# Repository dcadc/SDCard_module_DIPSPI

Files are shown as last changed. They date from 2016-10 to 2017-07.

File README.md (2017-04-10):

# SDCard_module_DIPSPI
這是一個和 Taiwanduino 相容的 microSD 記憶卡擴充板  
他可以直接取代原本所使用的 25AA512 EEPROM 記憶體

**使用說明**
* TaiwanDuino :   
 [/software/Taiwanduino/example][sw] 資料夾內的程式碼使用 Arduino IDE 開啟  
 預設播放檔名為 0.wav ~ 7.wav 的 PCM 編碼音訊檔  
 [安裝相對應的程式庫][libs]之後即可編譯上傳  
  
*** 
  
*Read this in other languages: [English](README.en.md), [正體中文](README.md).*  

   [sw]: <https://github.com/dcadc/SDCard_module_DIPSPI/tree/master/software/Taiwanduino/example/>
   [libs]: <https://github.com/dcadc/SDCard_module_DIPSPI/blob/master/software/Taiwanduino/README.md>

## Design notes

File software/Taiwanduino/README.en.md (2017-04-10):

# Software for Taiwanduino  
   If you have the latest Arduino IDE, you can also use *Board Manager* and *Library Manager* to download and import these automatically.
  
- Board Configs   
	 - [File] → [Preferences] → [Additional Board Manager URLs] and insert the URL below:
	   https://will127534.github.io/Taiwanduino/package_Taiwanduino_index.json   
	 - [Tools] → [Board: ""] → [Board Manager] and search for "Taiwanduino".  
	 - Click the [Install] button.  
 
- External libraries   
	 - [Sketch] → [Iclude library] → [Manage Libraries] and search for "TMRpcm"  
	 - Click the [Install] button.  
	 - The library could be found in  [TMRh20/TMRpcm](https://github.com/TMRh20/TMRpcm) if you want to import it manually.   
	 - [Sketch] → [Iclude library] → [Manage Libraries] and search for "CapacitiveSensor"  
	 - Click the [Install] button.  
	 - The library could be found in  [PaulStoffregen/CapacitiveSensor](https://github.com/PaulStoffregen/CapacitiveSensor) if you want to import it manually.  
  
***
  
*Read this in other languages: [English](README.en.md), [正體中文](README.md).*

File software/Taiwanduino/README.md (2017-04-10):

# Software for Taiwanduino  
請使用內建的 [板子管理員] 及 [管理程式庫] 功能來自動建立環境  
 - 板子編譯資訊  
	 - 請在 [檔案] → [偏好設定] → [額外的板子管理員網址] 中輸入以下網址：  
	 - https://will127534.github.io/Taiwanduino/package_Taiwanduino_index.json   
	 - 進入[工具] → [板子] → [板子管理員]中輸入搜尋 Taiwanduino  
	 - 按下[安裝]按鈕  

 - 所使用的外部函式庫  
	 - [草稿碼] → [匯入程式庫] → [管理程式庫]中輸入 TMRpcm 搜尋  
	 - 按下 [安裝] 按鈕  
	 - 手動匯入外部程式庫請至 [TMRh20/TMRpcm](https://github.com/TMRh20/TMRpcm) 下載
	 - [草稿碼] → [匯入程式庫] → [管理程式庫]中輸入 CapacitiveSensor 搜尋  
	 - 按下 [安裝] 按鈕  
	 - 手動匯入外部程式庫請至 [PaulStoffregen/CapacitiveSensor](https://github.com/PaulStoffregen/CapacitiveSensor) 下載  
  
***
  
*Read this in other languages: [English](README.en.md), [正體中文](README.md).*

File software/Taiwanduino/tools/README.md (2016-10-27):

# pcm_converter
把有帶音訊資料的任意影音檔案，透過拖曳的方式快速轉檔   
  
直接將主程式 ( .bat ) 檔建立一個捷徑並傳送到音效檔得資料夾  
比所要轉換的一個或多個音效檔案拖曳到剛剛建立的捷徑上面即可完成轉檔  
第一次使用會先下載一份libav的轉檔器  
所輸出的檔案將會是 8位元的 PCM 編碼 WAV 檔  
預設取樣率和輸出資料夾可以至程式中進行手動更改

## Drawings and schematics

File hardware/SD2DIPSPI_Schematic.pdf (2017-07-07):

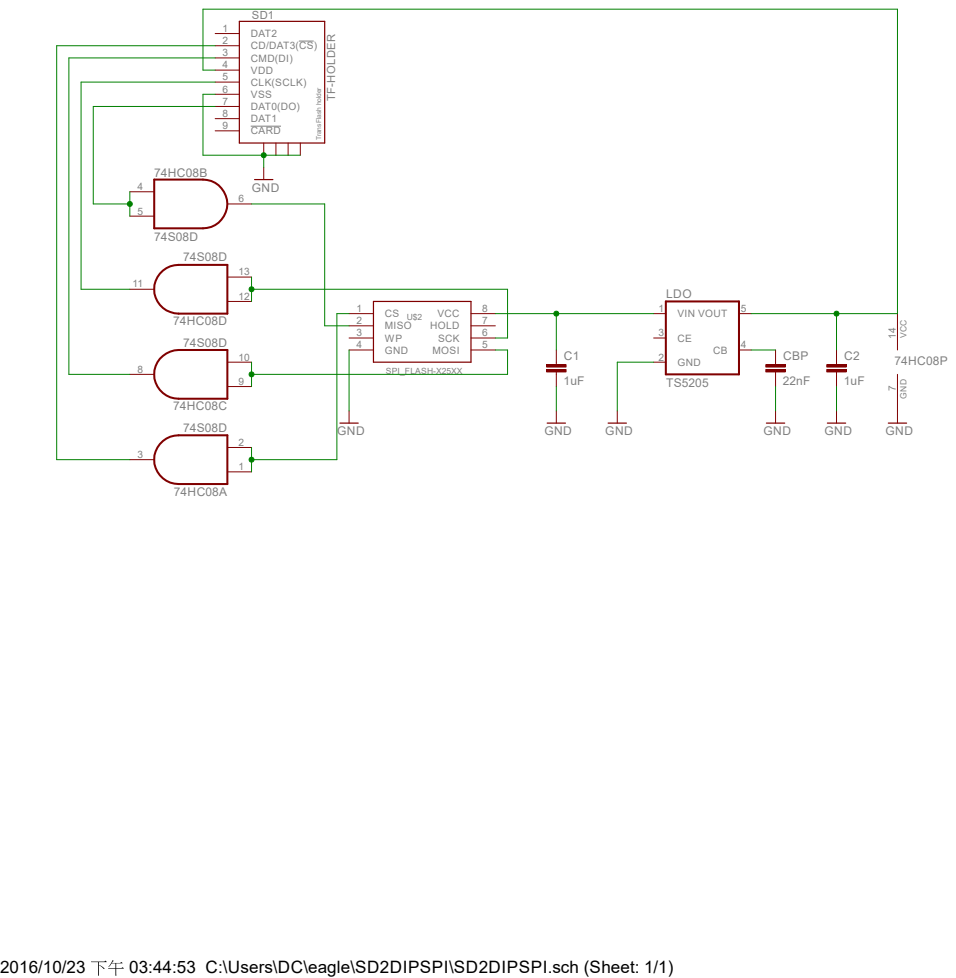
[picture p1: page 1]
03:44:53 C:\Users\DC\eagle\SD2DIPSPI\SD2DIPSPI.sch (Sheet: 1/1) TransFlash holder; TF⁻HOLDER; GND; SPI_FLASH-X25XX; SD1 DAT2 1 CD/DAT3(CS) 2; CLK(SCLK) 5 VSS 6 DAT0(DO) 7 DAT1 8 CARD 9; 74HC08P GND VCC 7 14; CS 1 MISO 2 WP 3 GND 4; VCC; HOLD; SCK; MOSI; LDO VIN 1; GND 2; VOUT; CBP

CMD(DI) 3
VDD 4

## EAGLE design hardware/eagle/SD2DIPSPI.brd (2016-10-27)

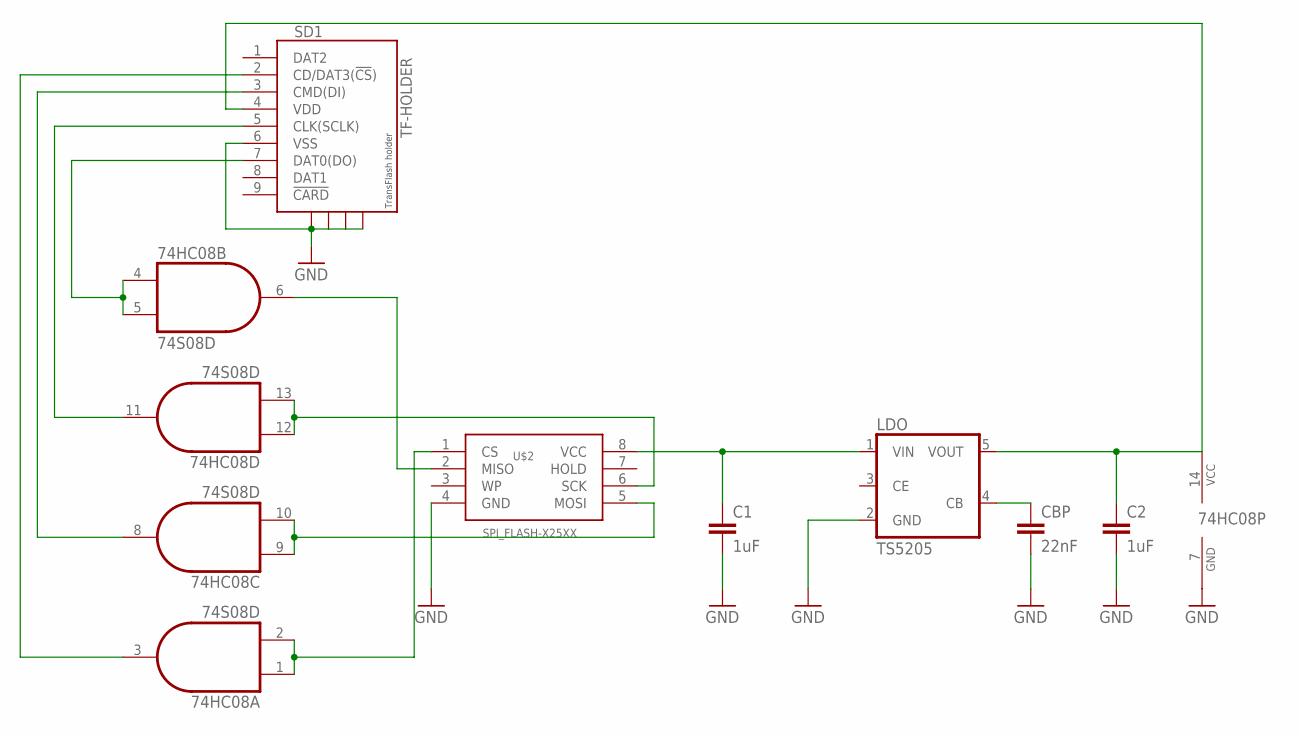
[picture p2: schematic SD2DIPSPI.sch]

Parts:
74HC08: 74S08D; SO14
C1, C2: 1uF; 0603-CAP
CBP: 22nF; 0402-CAP
LDO: TS5205; SOT25
SD1: TF-HOLDER; TF-PULL
U$2: SPI_FLASH-X25XX; DIL08

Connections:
3V3: 74HC08.14 (VCC), C2.1, LDO.5 (VOUT), SD1.4 (VDD)
+5V: C1.1, LDO.1 (VIN), U$2.8 (VCC)
GND: 74HC08.7 (GND), C1.2, C2.2, CBP.2, LDO.2 (GND), SD1.6 (VSS), SD1.S1, SD1.S2, SD1.S3, SD1.S4, U$2.4 (GND)
unnamed: CBP.1, LDO.4 (CB)
unnamed: 74HC08.9 (I0), 74HC08.10 (I1), U$2.5 (MOSI)
unnamed: 74HC08.12 (I0), 74HC08.13 (I1), U$2.6 (SCK)
unnamed: 74HC08.1 (I0), 74HC08.2 (I1), U$2.1 (CS)
unnamed: 74HC08.11 (O), SD1.5 (CLK(SCLK))
unnamed: 74HC08.8 (O), SD1.3 (CMD(DI))
unnamed: 74HC08.3 (O), SD1.2 (CD/DAT3(!CS!))
unnamed: 74HC08.6 (O), U$2.2 (MISO)
unnamed: 74HC08.4 (I0), 74HC08.5 (I1), SD1.7 (DAT0(DO))

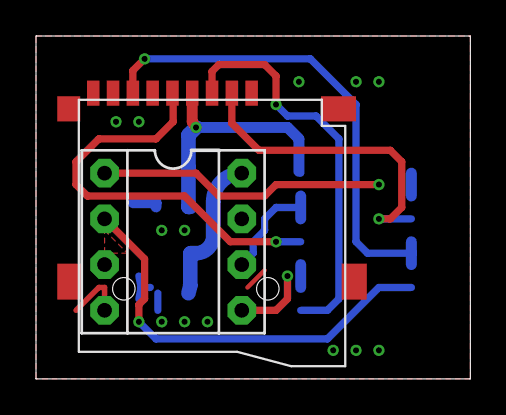
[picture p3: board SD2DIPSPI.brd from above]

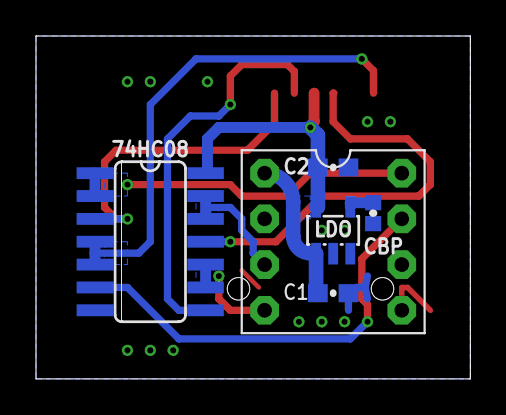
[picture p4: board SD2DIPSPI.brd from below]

Board: 2 copper layers, 24.1 x 19.1 mm, 7 parts (5 on the bottom side), 12 nets.

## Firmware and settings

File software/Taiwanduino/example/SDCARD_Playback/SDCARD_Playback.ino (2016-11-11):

#include <CapacitiveSensor.h>
#include <TMRpcm.h>
#include <SD.h>
#include <SPI.h>

#define SD_ChipSelectPin 10 //using digital pin 4 on arduino nano 328
#define buffSize 512		//set TMRpcm buffer size to 1 block of SDCARD
#define DISABLE_SPEAKER2	//Disables default second speaker pin for compatibility with other libs.
#define Threadhold 200		//scan button threadhold

int input_pin[7] = {A2,A4,A5,5,6,7,8};	//define touchpad pinouts
CapacitiveSensor *input[7];				//create an CapacitiveSensor object for use in this sketch
byte SDCARD_EN = 0;

TMRpcm tmrpcm;							// create an TMRpcm object for use in this sketch

/*
//TW Number 1 from our greatest Angrypug
const unsigned char sounddata_data[] PROGMEM = {0xfd,0x79,0x71,0x70,0x71,0x7f,0x8b,0x8a,0x8e,0x90,0x8e,0x88,0x7c,0x80,0x85,0x7f,0x76,0x71,0x71,0x74,0x76,0x7a,0x86,0x8b,0x8e,0x8f,0x96,0x94,0x88,0x7b,0x78,0x7e,0x7e,0x79,0x71,0x74,0x79,0x7a,0x77,0x7f,0x8a,0x93,0x93,0x8b,0x7d,0x78,0x7e,0x77,0x79,0x7b,0x79,0x7d,0x73,0x6d,0x7e,0x87,0x82,0x81,0x86,0x8a,0x8b,0x86,0x7a,0x7d,0x7f,0x73,0x77,0x7b,0x7b,0x7b,0x7d,0x82,0x80,0x80,0x7f,0x81,0x7f,0x7d,0x7c,0x87,0x8d,0x83,0x7b,0x7a,0x85,0x8c,0x8b,0x7c,0x71,0x7a,0x78,0x71,0x75,0x75,0x7a,0x7d,0x76,0x7c,0x8d,0x95,0x92,0x85,0x7e,0x7e,0x80,0x85,0x7c,0x7a,0x7e,0x7b,0x7d,0x80,0x84,0x88,0x7f,0x82,0x8a,0x84,0x7d,0x82,0x83,0x7a,0x79,0x7e,0x7d,0x70,0x73,0x82,0x8e,0x8a,0x7d,0x7a,0x7b,0x76,0x73,0x82,0x80,0x7b,0x74,0x6d,0x82,0x91,0x87,0x86,0x89,0x87,0x8a,0x89,0x83,0x79,0x88,0x8e,0x8a,0x7f,0x70,0x70,0x71,0x7d,0x90,0x82,0x6a,0x73,0x72,0x88,0x8d,0x75,0x71,0x76,0x7b,0x92,0xa7,0x8f,0x7e,0x71,0x6b,0x7a,0x82,0x86,0x86,0x82,0x85,0x88,0x88,0x85,0x88,0x90,0x93,0x7d,0x70,0x71,0x72,0x7c,0x87,0x8f,0x89,0x80,0x64,0x63,0x6c,0x83,0x65,0x7d,0xcd,0x96,0x7e,0x5b,0x4c,0x99,0xa4,0x77,0x76,0x68,0x79,0x9a,0x7d,0x8b,0x90,0x93,0x9c,0x7d,0x62,0x7e,0x9f,0x99,0x7d,0x58,0x6a,0x8c,0x89,0x66,0x49,0x33,0x83,0xe4,0xa7,0x7a,0x54,0x46,0x9f,0xb6,0x8e,0x7f,0x7f,0x89,0x8e,0x7e,0x79,0x88,0x7b,0x6d,0x6c,0x8b,0xa6,0x79,0x5d,0x63,0x6e,0x94,0x84,0x45,0x33,0x72,0xf4,0xc3,0x64,0x51,0x2e,0xb0,0xe6,0x7a,0x57,0x5b,0x7e,0xc4,0x97,0x71,0x79,0x5b,0x88,0xaf,0x97,0x70,0x50,0x4e,0x85,0x9a,0x87,0x56,0x3b,0xd6,0xef,0x58,0x49,0x1d,0x5c,0xf4,0xc4,0x79,0x4e,0x45,0x91,0xa2,0x6d,0x84,0x77,0x93,0xb3,0x62,0x3a,0x46,0x73,0x9c,0x8f,0x30,0x62,0xfd,0xb1,0x54,0x3f,0x6,0x99,0xfe,0x81,0x89,0x5c,0x2c,0xb8,0x91,0x54,0x87,0x87,0xaf,0x9c,0x2f,0x41,0x54,0x73,0x7f,0x42,0xc5,0xeb,0x52,0x44,0x19,0x29,0xf0,0xbd,0x76,0x93,0x40,0x85,0x9a,0x32,0x74,0xb1,0xc7,0xc9,0x35,0x6,0x40,0x6a,0x74,0x96,0xff,0xbb,0x52,0x3e,0x6,0x79,0xf8,0xb3,0xc0,0x79,0x40,0x80,0x3c,0x5e,0xc8,0xb4,0x9c,0x74,0xb,0x2f,0x64,0x5e,0xcc,0xff,0x69,0x45,0x48,0x0,0xb5,0xe4,0x92,0xd1,0x73,0x4b,0x8e,0x3a,0x64,0xcf,0xb0,0x91,0x46,0xe,0x35,0x3d,0x96,0xff,0x9b,0x38,0x7b,0x9,0x6e,0xff,0x4c,0x7f,0xc1,0x55,0xa6,0x83,0x1b,0xa4,0xc6,0x86,0x74,0x2d,0x1f,0x45,0x80,0xf8,0xaa,0x29,0x74,0x32,0x6f,0xfd,0x57,0x59,0xae,0x53,0xa2,0xba,0x48,0x91,0xa6,0x68,0x6c,0x43,0x2a,0x58,0xa0,0xf7,0x77,0x12,0x56,0x28,0xac,0xfa,0x3e,0x7a,0xad,0x36,0xa1,0x89,0x5d,0xe1,0xc0,0x6c,0x45,0x19,0x17,0x89,0xe6,0xd6,0x47,0x1a,0x2c,0x46,0xee,0xb9,0x36,0xa4,0x76,0x5a,0xc8,0x5b,0x81,0xd0,0x90,0x77,0x5c,0x15,0x24,0xb8,0xff,0x79,0x25,0x39,0x18,0xb4,0xf2,0x4e,0x55,0x89,0x54,0xbe,0xa0,0x67,0xbb,0xa4,0x72,0x4f,0x29,0x25,0x81,0xf7,0xd1,0x19,0x2c,0x13,0x4e,0xff,0xb4,0x47,0x88,0x4d,0x46,0xb7,0x80,0xa9,0xd1,0x91,0x49,0x3f,0x8,0x48,0xca,0xf7,0x68,0x13,0x27,0x16,0xbc,0xf5,0x6c,0x65,0x7c,0x29,0x97,0x99,0x85,0xcd,0xa4,0x4e,0x49,0x17,0x36,0xc1,0xf7,0xa1,0x1c,0xa,0xf,0xa5,0xf8,0x9d,0x64,0x78,0x31,0x68,0x88,0x8b,0xd1,0xb3,0x78,0x4d,0x17,0x1b,0xa3,0xef,0xcb,0x38,0x13,0xa,0x74,0xff,0xad,0x56,0x91,0x48,0x59,0x9e,0x6f,0xb5,0xb4,0x83,0x5c,0x31,0x12,0x7f,0xf3,0xdd,0x40,0x1d,0x11,0x4f,0xff,0xc8,0x50,0x8b,0x58,0x51,0xb2,0x78,0xa7,0xb6,0x86,0x5f,0x35,0x5,0x5d,0xe6,0xf1,0x52,0x18,0x16,0x36,0xea,0xe0,0x69,0x9c,0x5d,0x2f,0xb2,0x8c,0xac,0xbd,0x80,0x59,0x4a,0xb,0x50,0xdb,0xf4,0x6c,0x1a,0x15,0x21,0xcf,0xeb,0x87,0x9d,0x6c,0x19,0x8e,0xa0,0xbf,0xd2,0x85,0x4a,0x4e,0x14,0x44,0xd1,0xec,0x76,0x20,0x1d,0xf,0xb4,0xee,0x8f,0x9d,0x72,0x16,0x7c,0x9d,0xb7,0xda,0x9c,0x53,0x52,0x17,0x2f,0xce,0xef,0x7a,0x2e,0x20,0x11,0xc3,0xed,0x89,0xa3,0x79,0x29,0x72,0x82,0xa4,0xbb,0x9c,0x74,0x56,0x20,0x43,0xc8,0xff,0x91,0x20,0x26,0xe,0xac,0xfe,0x81,0x83,0x8e,0x3e,0x78,0x8a,0x92,0xb6,0xa6,0x7c,0x54,0x13,0x35,0xcd,0xf8,0x95,0x33,0x23,0x22,0xbd,0xe9,0x80,0x89,0x74,0x53,0x9d,0x87,0x8a,0xb1,0x86,0x7e,0x61,0x13,0x40,0xdb,0xec,0x7f,0x41,0x20,0x2d,0xdb,0xd6,0x67,0xa5,0x7b,0x65,0xb9,0x80,0x72,0x9e,0x79,0x88,0x6e,0x13,0x65,0xe7,0xd1,0x72,0x43,0x1f,0x5d,0xed,0xaf,0x6c,0x8f,0x62,0x83,0xb3,0x94,0x8f,0x85,0x81,0x8a,0x3c,0x13,0x98,0xfb,0xb1,0x5a,0x3c,0x12,0x88,0xff,0x83,0x70,0x8d,0x47,0x93,0xb8,0x84,0x9f,0x89,0x61,0x8b,0x47,0x29,0xc9,0xf0,0x5f,0x57,0x55,0x1e,0xc9,0xec,0x50,0x7a,0x81,0x4b,0xa8,0xae,0x88,0x94,0x57,0x5d,0x78,0x3a,0x75,0xff,0xc2,0x42,0x5a,0x32,0x4f,0xec,0xa9,0x58,0x86,0x63,0x6f,0xa1,0x9c,0xb5,0x95,0x48,0x68,0x53,0x2c,0xa6,0xf6,0x7a,0x35,0x4c,0x1a,0x9f,0xfc,0x7d,0x78,0x7d,0x50,0x8c,0x99,0x8d,0xb5,0x74,0x4c,0x6e,0x37,0x5c,0xeb,0xd7,0x3e,0x3a,0x36,0x42,0xe6,0xb6,0x48,0x7f,0x5a,0x69,0xc5,0xa2,0xa9,0x9d,0x43,0x5f,0x57,0x29,0xa2,0xf7,0x85,0x28,0x46,0x32,0x96,0xf7,0x74,0x57,0x7b,0x57,0x9b,0xb2,0x80,0xa6,0x76,0x4d,0x6f,0x38,0x59,0xe6,0xd3,0x41,0x2a,0x37,0x56,0xe8,0xc1,0x4b,0x5f,0x56,0x78,0xc9,0x98,0x89,0x9c,0x53,0x5f,0x48,0x1d,0xa2,0xff,0x8e,0x31,0x37,0x26,0xa3,0xfb,0x7d,0x5a,0x58,0x4c,0xaf,0xc4,0x91,0xab,0x74,0x49,0x65,0x1c,0x53,0xee,0xc8,0x46,0x3d,0x26,0x4f,0xf7,0xd0,0x70,0x6a,0x44,0x70,0xb9,0xa1,0xa3,0x98,0x54,0x5f,0x40,0x2a,0xb2,0xfb,0x7d,0x25,0x33,0x21,0x9c,0xeb,0x81,0x65,0x58,0x4b,0x9b,0xb8,0xa7,0xb1,0x77,0x5c,0x57,0x18,0x65,0xee,0xc3,0x47,0x43,0x27,0x5a,0xf3,0xb8,0x6a,0x67,0x45,0x6e,0xaa,0x94,0xa1,0x8e,0x61,0x6f,0x3a,0x35,0xcb,0xf6,0x6d,0x3d,0x40,0x37,0xcb,0xec,0x71,0x60,0x54,0x55,0xab,0xa7,0x92,0xab,0x5d,0x66,0x69,0x22,0x8d,0xff,0x8e,0x2f,0x3a,0x19,0x9a,0xff,0x97,0x73,0x64,0x40,0x91,0xc5,0x92,0xaa,0x7d,0x3d,0x65,0x3d,0x5f,0xf7,0xdb,0x43,0x3a,0x25,0x43,0xf1,0xc4,0x52,0x62,0x42,0x52,0xbd,0xb6,0xa1,0xa3,0x60,0x59,0x4d,0x54,0xc0,0xfb,0x73,0x1e,0x36,0x32,0xbb,0xef,0x76,0x59,0x56,0x4e,0xa9,0xb8,0x93,0xa5,0x62,0x5a,0x5f,0x24,0x8b,0xfb,0xa4,0x3c,0x44,0x22,0x92,0xff,0x87,0x6a,0x5b,0x3a,0x96,0xcd,0x81,0x9b,0x8e,0x47,0x68,0x4e,0x5f,0xe8,0xcf,0x34,0x35,0x2c,0x4f,0xf2,0xbb,0x55,0x63,0x50,0x7f,0xcd,0xb2,0x91,0x8a,0x5e,0x5d,0x2f,0x51,0xcf,0xdb,0x63,0x29,0x33,0x41,0xda,0xde,0x70,0x5d,0x57,0x5b,0xa1,0xa1,0x87,0xa1,0x72,0x68,0x4d,0x2f,0xad,0xff,0x95,0x35,0x37,0x2d,0x9e,0xf7,0x86,0x5b,0x5d,0x5b,0x8b,0xb3,0x98,0x9e,0x7d,0x57,0x3f,0x25,0x91,0xf9,0x98,0x2b,0x44,0x2c,0x97,0xff,0x82,0x5b,0x74,0x47,0x95,0xa9,0x71,0x9e,0x86,0x59,0x61,0x2e,0x6b,0xf5,0xcb,0x44,0x39,0x4e,0x6b,0xf0,0xbb,0x4a,0x4d,0x6b,0x7f,0xa4,0x93,0x86,0x8c,0x7e,0x69,0x1b,0x62,0xf8,0xb8,0x38,0x4c,0x21,0x6d,0xff,0x94,0x60,0x75,0x3e,0x97,0xc0,0x63,0x7a,0x9e,0x65,0x62,0x48,0x46,0xd1,0xea,0x57,0x2f,0x60,0x61,0xd8,0xcf,0x5e,0x4f,0x63,0x7f,0xa6,0x8e,0x72,0x86,0x87,0x7a,0x20,0x4e,0xf4,0xc6,0x3f,0x4e,0x2a,0x59,0xf5,0x96,0x4c,0x8b,0x4c,0x7b,0xce,0x6a,0x6d,0xb3,0x6d,0x76,0x51,0x2f,0xd5,0xee,0x44,0x2e,0x63,0x62,0xef,0xc4,0x3d,0x5b,0x8a,0x8f,0xa9,0x75,0x5a,0x87,0x86,0x6a,0x23,0x75,0xff,0xa4,0x21,0x52,0x37,0x9a,0xff,0x62,0x32,0x7a,0x61,0xa9,0xd1,0x58,0x70,0xac,0x6e,0x6b,0x3d,0x57,0xf2,0xd5,0x2a,0x26,0x58,0x9b,0xff,0xa0,0x2a,0x53,0x9f,0xb8,0xa8,0x5b,0x68,0x93,0x8f,0x52,0x17,0x90,0xff,0x80,0x1d,0x46,0x49,0xc4,0xf2,0x52,0x45,0x79,0x59,0xa5,0xbb,0x66,0x93,0xa7,0x56,0x50,0x37,0x83,0xff,0xb8,0x18,0x32,0x64,0xa4,0xfb,0x85,0x29,0x71,0x90,0x9d,0x98,0x5b,0x90,0xb5,0x69,0x1f,0x3a,0xce,0xe9,0x42,0x18,0x40,0x70,0xf0,0xbf,0x26,0x70,0x86,0x61,0xc6,0xad,0x57,0x98,0xa1,0x4e,0x32,0x51,0xc5,0xf4,0x6d,0xf,0x53,0x8c,0xe7,0xce,0x3c,0x48,0x91,0x94,0x91,0x73,0x7f,0x9d,0x87,0x48,0x18,0xa7,0xff,0x7a,0x16,0x5b,0x6c,0xc6,0xed,0x32,0x53,0xc2,0x59,0x78,0xb3,0x75,0xa9,0xa2,0x4e,0x3c,0x34,0xa0,0xff,0x80,0xa,0x5f,0x76,0xba,0xed,0x43,0x4b,0xb3,0x8a,0x7d,0x87,0x76,0xb0,0x98,0x40,0x1e,0x71,0xf9,0xaf,0x19,0x43,0x74,0x92,0xfe,0x69,0x38,0xca,0x72,0x46,0x9f,0x74,0x8e,0xd6,0x62,0x2d,0x2f,0x66,0xf0,0xcc,0x1f,0x48,0x94,0x95,0xd4,0x74,0x4a,0xa4,0x9d,0x77,0x75,0x62,0x92,0xb2,0x77,0x29,0x27,0xcd,0xf3,0x3c,0x1b,0x81,0x72,0xde,0xb4,0xe,0x9f,0xc1,0x45,0x7c,0x91,0x5c,0xc5,0xa9,0x53,0x4c,0x43,0xbb,0xf1,0x3b,0x2b,0xa4,0x7a,0xbe,0x9c,0x20,0x7f,0xc8,0x72,0x7d,0x81,0x56,0xa1,0x90,0x23,0x39,0xd9,0xe1,0x3e,0x2e,0x8e,0x74,0xc5,0xb9,0x2a,0x9e,0xc1,0x4a,0x6e,0x9b,0x5c,0x92,0x9f,0x5d,0x4e,0x51,0xba,0xe4,0x34,0x32,0xa3,0x72,0xba,0x8a,0x2b,0x9f,0xa2,0x58,0x94,0x89,0x74,0xac,0x6f,0x35,0x39,0xae,0xff,0x55,0xc,0xa2,0x67,0x8b,0xca,0x20,0x8f,0xf2,0x4a,0x4f,0x9f,0x51,0x8f,0xbe,0x4f,0x4b,0x64,0xa2,0xe8,0x4f,0x1b,0xa4,0x90,0xaa,0x9c,0x43,0x94,0xad,0x64,0x88,0x8d,0x5d,0x9c,0x9b,0x3e,0x28,0xa3,0xff,0x63,0x19,0xa5,0x78,0x90,0xc6,0x1a,0x76,0xf0,0x59,0x4f,0xac,0x60,0x6d,0xac,0x7b,0x5c,0x51,0xad,0xec,0x49,0x37,0xaa,0x68,0xaa,0xb3,0x30,0x90,0xb9,0x41,0x7a,0xb7,0x69,0x95,0x90,0x2d,0x38,0x9c,0xfa,0x79,0xd,0xac,0x84,0x68,0xd2,0x3d,0x68,0xf9,0x62,0x4d,0xb5,0x65,0x75,0xb2,0x68,0x56,0x54,0xa3,0xfb,0x51,0x2d,0xbd,0x63,0x98,0xce,0x2d,0x84,0xd1,0x4b,0x77,0xa2,0x5f,0x93,0x93,0x51,0x3e,0x93,0xff,0x7b,0x13,0xb9,0x89,0x57,0xce,0x49,0x56,0xf8,0x68,0x3b,0xc4,0x66,0x66,0xb8,0x53,0x56,0x75,0xa5,0xf6,0x54,0x33,0xc7,0x5d,0x7d,0xc5,0x2e,0x90,0xe1,0x3d,0x79,0xbb,0x56,0x94,0x8f,0x4c,0x59,0x70,0xde,0xbb,0x1b,0x93,0xae,0x45,0xba,0x75,0x3f,0xd4,0xab,0x56,0x9b,0x77,0x6b,0xb0,0x64,0x34,0x61,0x9c,0xf4,0xaa,0x27,0x9b,0x7e,0x72,0xc1,0x32,0x5d,0xdc,0x87,0x86,0xaa,0x4d,0x8e,0xb0,0x45,0x3f,0x4c,0x96,0xff,0x66,0x39,0xd1,0x4f,0x75,0xad,0x24,0x96,0xe8,0x6a,0x8f,0xa6,0x3f,0x9f,0x97,0x1b,0x3d,0x5f,0xb0,0xf6,0x4f,0x6e,0xb7,0x3e,0xa6,0x84,0xe,0xb0,0xd0,0x6f,0xb8,0x7f,0x44,0xb1,0x7d,0x3d,0x49,0x44,0xb8,0xfc,0x57,0x5d,0xb0,0x56,0x8e,0x72,0x1a,0x96,0xcd,0x9a,0xaf,0x82,0x5f,0x9f,0x5f,0x39,0x2e,0x31,0xce,0xef,0x53,0x85,0x8a,0x44,0xb4,0x5a,0x17,0x93,0xc7,0xa4,0xc0,0x99,0x5f,0xa9,0x63,0x24,0x2e,0x27,0xa3,0xff,0x7f,0x5d,0xb3,0x59,0x7a,0x68,0x2,0x4c,0xa4,0xc7,0xe1,0xba,0x77,0x77,0x5d,0x4c,0x20,0xe,0x9a,0xff,0xa2,0x90,0xba,0x4d,0x7d,0x8a,0xc,0x39,0x97,0xbb,0xd6,0xe3,0x7a,0x5b,0x8a,0x56,0x1b,0x3,0x76,0xff,0xad,0x87,0xda,0x5e,0x7a,0xb0,0x1f,0x2b,0x78,0x8d,0xb3,0xf2,0x91,0x4e,0x9f,0x76,0x3c,0x22,0x28,0xc4,0xce,0x80,0xd0,0x9d,0x5e,0xab,0x67,0x1b,0x46,0x61,0x9b,0xcf,0xb1,0x70,0x7c,0x75,0x57,0x3a,0x47,0xbc,0x91,0x85,0xe9,0xa1,0x87,0xc8,0x60,0x23,0x68,0x52,0x6f,0xc9,0xaa,0x7a,0xa2,0x75,0x48,0x4a,0x50,0xa6,0x78,0x65,0xc2,0xa3,0x9f,0xd5,0x8b,0x3d,0x5c,0x67,0x81,0xba,0x9e,0x70,0x82,0x77,0x64,0x5b,0x84,0xa8,0x63,0x72,0x93,0x6f,0xa7,0xb0,0x69,0x6b,0x60,0x51,0x94,0xb4,0x7a,0x78,0x76,0x55,0x6e,0x7d,0xa7,0x9e,0x6e,0x93,0x7a,0x80,0xb0,0x78,0x59,0x6b,0x5a,0x6a,0xb1,0xaf,0x7e,0x89,0x6d,0x4a,0x67,0x85,0xb0,0x91,0x7c,0x82,0x63,0xa5,0xc3,0x73,0x70,0x7b,0x41,0x75,0xba,0x89,0x8d,0x91,0x52,0x60,0x89,0x9c,0xa9,0x8e,0x7c,0x56,0x56,0xb5,0xbc,0x93,0x94,0x59,0x40,0x92,0xaf,0x9b,0x8c,0x57,0x37,0x4e,0x7b,0xc6,0xc7,0xa3,0x9b,0x3e,0x4a,0xac,0xa7,0xa8,0x9d,0x4e,0x3e,0x82,0xa0,0xa8,0xa8,0x5a,0x34,0x4c,0x6d,0xb5,0xc1,0xc6,0x9b,0x3e,0x5d,0x80,0x8c,0xb8,0x97,0x59,0x50,0x62,0x7f,0xb0,0xab,0x71,0x51,0x3c,0x5b,0x80,0xa4,0xd9,0x8f,0x6b,0x80,0x51,0x87,0xa4,0x84,0x8e,0x73,0x58,0x7a,0x9d,0x7f,0x7e,0x7f,0x70,0x71,0x64,0x9c,0x9e,0x7d,0xb2,0x85,0x77,0x98,0x5c,0x65,0x8c,0x6f,0x6f,0x9d,0x84,0x6a,0x73,0x6e,0x92,0x7e,0x85,0xb7,0x7b,0x88,0x90,0x5d,0xa6,0x9e,0x5c,0x89,0x83,0x59,0x84,0x9f,0x70,0x74,0x77,0x80,0x92,0x6e,0x9f,0x8f,0x75,0xaf,0x6b,0x7a,0xb2,0x6f,0x76,0x88,0x61,0x6b,0x97,0x81,0x71,0x6f,0x64,0x89,0x7b,0x95,0xa7,0x71,0xa7,0x8c,0x56,0xa1,0x82,0x68,0x91,0x7b,0x68,0x80,0x76,0x65,0x73,0x6d,0x8f,0x7a,0x7e,0xb7,0x73,0x8d,0xa5,0x5c,0x8f,0x8d,0x68,0x83,0x77,0x6b,0x86,0x86,0x6e,0x72,0x52,0x75,0xa3,0x75,0xae,0xa8,0x7e,0xa9,0x7b,0x7f,0x91,0x83,0x80,0x6d,0x7c,0x78,0x80,0x91,0x8c,0x67,0x5d,0x85,0x6e,0x89,0xad,0x96,0xac,0x87,0x79,0x82,0x67,0x92,0x82,0x6b,0x6f,0x6e,0x7f,0x7b,0x81,0x68,0x76,0x79,0x79,0x94,0x8b,0xbf,0xac,0x84,0x9a,0x62,0x6b,0x7a,0x6b,0x84,0x74,0x81,0x83,0x7d,0x6c,0x7e,0x85,0x66,0x9c,0x7b,0x7d,0xc5,0x97,0xa1,0x93,0x5c,0x71,0x5b,0x67,0x6e,0x69,0x85,0x84,0x73,0x63,0x8d,0x71,0x74,0x9b,0x63,0x8f,0xa4,0x9f,0xbb,0x8d,0x7f,0x68,0x59,0x78,0x58,0x5d,0x7d,0x81,0x6b,0x81,0xa1,0x63,0x7d,0x73,0x5e,0x8f,0x80,0xa9,0xbb,0x99,0x94,0x6f,0x63,0x6e,0x5f,0x6b,0x77,0x6f,0x72,0x9d,0x91,0x72,0x8d,0x7a,0x84,0xa4,0x94,0xa1,0x91,0x90,0x8c,0x68,0x7f,0x70,0x4a,0x64,0x7b,0x6c,0x86,0xa7,0x86,0x80,0x87,0x68,0x91,0xa0,0xa3,0xb1,0x8d,0x91,0x78,0x6b,0x7b,0x50,0x63,0x89,0x72,0x7c,0x8b,0x8a,0x79,0x8e,0x8c,0x90,0xa5,0x7c,0x91,0x8a,0x8e,0xad,0x6e,0x64,0x7d,0x55,0x66,0x84,0x6a,0x6d,0x91,0x8b,0x80,0x90,0x77,0x88,0x86,0x84,0xb0,0x90,0x97,0x8d,0x64,0x74,0x6c,0x62,0x7e,0x77,0x6d,0x78,0x7b,0x74,0x7f,0x7d,0x78,0x99,0x84,0x90,0xab,0x88,0x98,0x83,0x5d,0x77,0x63,0x5f,0x74,0x71,0x69,0x79,0x7d,0x6b,0x83,0x7a,0x94,0xa6,0x89,0xb4,0xa7,0x81,0x90,0x6d,0x64,0x6a,0x5c,0x63,0x6a,0x60,0x70,0x8c,0x80,0x89,0x8d,0x7b,0xa5,0xa0,0x94,0xb0,0x89,0x92,0x88,0x63,0x6f,0x63,0x67,0x6d,0x6d,0x6a,0x7f,0x8c,0x80,0x90,0x7e,0x8f,0xa4,0x88,0xa3,0x98,0x81,0x8d,0x6e,0x68,0x6b,0x62,0x6d,0x75,0x65,0x63,0x84,0x81,0x86,0x89,0x7a,0x98,0x96,0x91,0xa3,0x8a,0x88,0x83,0x69,0x71,0x6d,0x6a,0x7f,0x77,0x66,0x78,0x78,0x83,0x9b,0x7e,0x91,0xa6,0x88,0x9f,0x91,0x79,0x8a,0x71,0x66,0x75,0x6c,0x6c,0x83,0x70,0x68,0x7e,0x71,0x91,0x9c,0x84,0xa8,0x99,0x8f,0x9f,0x78,0x7d,0x7c,0x61,0x77,0x79,0x6a,0x76,0x7c,0x6b,0x76,0x7a,0x6f,0x98,0x8b,0x8c,0xaf,0x95,0x9b,0x8c,0x6b,0x76,0x66,0x5a,0x72,0x7f,0x73,0x81,0x77,0x5d,0x81,0x7a,0x7a,0xa0,0x89,0x9a,0xaa,0x90,0x9e,0x7e,0x6c,0x7a,0x5a,0x5c,0x76,0x72,0x7e,0x8d,0x73,0x6f,0x81,0x6b,0x78,0x9b,0x81,0xa0,0xa7,0x8d,0x9f,0x6f,0x6d,0x78,0x55,0x60,0x7e,0x80,0x86,0x90,0x72,0x6a,0x7e,0x67,0x6f,0x9e,0x86,0x9c,0xa6,0x8b,0x9e,0x6f,0x71,0x76,0x5a,0x70,0x7d,0x82,0x85,0x8e,0x80,0x71,0x7d,0x68,0x64,0x8b,0x7c,0x92,0xaa,0x8b,0x9c,0x7d,0x6b,0x6e,0x53,0x64,0x81,0x89,0x8c,0x91,0x76,0x6b,0x72,0x5f,0x60,0x93,0x92,0x8b,0xb8,0x91,0x8f,0x8b,0x68,0x73,0x62,0x6f,0x87,0x8f,0x92,0x8e,0x7a,0x65,0x69,0x68,0x5c,0x8d,0xa3,0x8b,0xbc,0x9f,0x80,0x92,0x60,0x64,0x71,0x64,0x8a,0xa1,0x93,0x8f,0x87,0x64,0x56,0x69,0x5c,0x8c,0xb2,0x8a,0xbd,0x9b,0x63,0x8b,0x61,0x5f,0x8d,0x70,0x85,0xab,0x83,0x88,0x82,0x5a,0x61,0x71,0x63,0x99,0xad,0x80,0xbd,0x86,0x5f,0x96,0x59,0x6d,0x9b,0x69,0x84,0xa0,0x6d,0x87,0x85,0x52,0x74,0x82,0x69,0xaa,0x99,0x73,0xb8,0x74,0x65,0x98,0x63,0x7f,0x9e,0x67,0x87,0x9a,0x6f,0x92,0x87,0x53,0x7b,0x7f,0x66,0xb2,0x8f,0x7a,0xbf,0x71,0x7a,0x97,0x58,0x8a,0x8d,0x5f,0x97,0x93,0x79,0xa2,0x7e,0x53,0x70,0x72,0x5e,0xa9,0x90,0x7d,0xbe,0x76,0x75,0x86,0x55,0x81,0x8f,0x6b,0x9c,0x95,0x86,0xa6,0x82,0x4a,0x6e,0x72,0x55,0xb8,0x96,0x7d,0xbb,0x79,0x75,0x9e,0x63,0x7d,0x8a,0x57,0x99,0x93,0x8a,0xa9,0x78,0x4a,0x5f,0x72,0x62,0xb4,0xa7,0x83,0xb8,0x71,0x6c,0x95,0x5a,0x67,0x87,0x65,0x9c,0xaf,0x8c,0x9f,0x74,0x3b,0x47,0x60,0x5a,0xac,0xbd,0x97,0xc1,0x7c,0x4c,0x79,0x42,0x4b,0x91,0x78,0xa5,0xbd,0x98,0x9e,0x85,0x3b,0x26,0x51,0x58,0x92,0xd9,0xab,0xad,0x9d,0x44,0x5d,0x5f,0x3f,0x80,0x8d,0x96,0xcc,0x9d,0x88,0x81,0x42,0x24,0x41,0x77,0x93,0xd1,0xd9,0x99,0x94,0x5f,0x2d,0x63,0x59,0x60,0xb1,0xa4,0xb6,0xc4,0x7b,0x75,0x5b,0x27,0x2c,0x55,0x90,0xb9,0xe6,0xd8,0x8c,0x7a,0x2f,0x16,0x5f,0x68,0x9a,0xd3,0xc2,0xc3,0xa4,0x56,0x53,0x34,0x2a,0x33,0x60,0xbd,0xcb,0xed,0xd5,0x68,0x51,0x24,0x12,0x75,0x9c,0xad,0xe9,0xbd,0x9b,0x96,0x3e,0x49,0x4c,0x2a,0x33,0x63,0xba,0xdf,0xf6,0xd5,0x58,0x29,0xd,0xa,0x95,0xc9,0xd0,0xef,0x8e,0x62,0x6c,0x33,0x57,0x69,0x40,0x3e,0x71,0xbc,0xdb,0xee,0xad,0x41,0x32,0x19,0x39,0xbc,0xcb,0xce,0xdb,0x69,0x56,0x64,0x41,0x8c,0x84,0x45,0x46,0x76,0xc3,0xdb,0xea,0x8d,0x22,0x24,0x8,0x63,0xf2,0xde,0xe7,0xb8,0x1e,0x3a,0x55,0x5b,0xad,0x8f,0x36,0x3e,0xa1,0xc6,0xd9,0xd9,0x4a,0x10,0x27,0x2f,0xb4,0xf6,0xcd,0xc1,0x51,0x1e,0x62,0x65,0x97,0xb2,0x5d,0x21,0x68,0xb8,0xc6,0xea,0x9a,0x1e,0x32,0x2b,0x6a,0xe6,0xd1,0xb7,0x89,0x21,0x43,0x84,0x8a,0xb1,0x87,0x24,0x26,0x9a,0xcd,0xdc,0xd5,0x45,0x26,0x46,0x4a,0xbb,0xdd,0x97,0x84,0x43,0x22,0x99,0xaf,0xa6,0xa1,0x44,0x6,0x61,0xe1,0xd7,0xe6,0x80,0xb,0x40,0x67,0xa8,0xf1,0xb5,0x64,0x4f,0x1c,0x7e,0xcd,0xaf,0xaf,0x5c,0x17,0x2c,0xb8,0xea,0xde,0xb3,0x29,0x22,0x62,0x96,0xd6,0xd6,0x64,0x4f,0x3b,0x59,0xd6,0xba,0x9f,0x6c,0x22,0x19,0x8a,0xe8,0xde,0xcb,0x51,0x13,0x4b,0x87,0xba,0xe3,0x85,0x3d,0x4c,0x3f,0xb4,0xd8,0x9f,0x75,0x36,0xc,0x47,0xd8,0xec,0xda,0x90,0x19,0x1c,0x78,0xa8,0xd8,0xcc,0x50,0x4a,0x49,0x72,0xce,0xb5,0x7d,0x59,0x2e,0x18,0xa3,0xf5,0xd1,0xbd,0x4a,0x1,0x61,0xa2,0xbc,0xed,0x72,0x3c,0x59,0x4d,0xb7,0xd0,0x8d,0x70,0x4d,0x10,0x57,0xe6,0xdb,0xbb,0x7f,0xc,0x28,0xa2,0xaf,0xdf,0xb6,0x33,0x53,0x4d,0x7e,0xd7,0xa5,0x70,0x61,0x28,0x1b,0xa7,0xf2,0xc4,0x9f,0x4a,0x5,0x71,0xb6,0xb3,0xdb,0x67,0x39,0x64,0x5d,0xb3,0xc6,0x79,0x67,0x51,0x15,0x57,0xd9,0xdb,0xab,0x81,0x21,0x28,0xa0,0xa6,0xcb,0xbe,0x41,0x59,0x5f,0x73,0xd5,0xaa,0x65,0x6a,0x2f,0x16,0xa1,0xee,0xbe,0xa3,0x53,0x6,0x6b,0xb1,0xb0,0xe4,0x7c,0x34,0x62,0x51,0xa9,0xd7,0x7e,0x69,0x57,0x12,0x48,0xd8,0xe7,0xb7,0x91,0x2e,0x1a,0x98,0xb4,0xbd,0xd0,0x51,0x43,0x62,0x6e,0xcc,0xc1,0x6d,0x5f,0x3f,0xc,0x85,0xf9,0xc9,0xa7,0x6f,0x6,0x4e,0xc6,0xa9,0xda,0xa2,0x23,0x59,0x5f,0x91,0xe3,0x96,0x57,0x61,0x1f,0x32,0xce,0xe6,0xb2,0x93,0x35,0xa,0x93,0xc4,0xaf,0xd8,0x59,0x2d,0x6d,0x68,0xba,0xd3,0x6a,0x54,0x4e,0xc,0x75,0xf2,0xcb,0xa5,0x72,0x9,0x3b,0xcb,0xb4,0xcf,0xb1,0x1d,0x4f,0x73,0x7f,0xd8,0xa0,0x44,0x63,0x34,0x2b,0xc9,0xe9,0xb0,0x93,0x3c,0x8,0x89,0xcd,0xb0,0xd6,0x65,0x23,0x6e,0x75,0xab,0xd1,0x69,0x40,0x5c,0x1f,0x68,0xf3,0xcf,0x90,0x6e,0x15,0x33,0xcf,0xbc,0xbc,0xb4,0x23,0x45,0x88,0x85,0xc7,0xa4,0x33,0x57,0x51,0x2a,0xb5,0xf4,0xa6,0x7b,0x49,0xa,0x81,0xde,0xa9,0xc4,0x74,0x25,0x6e,0x89,0xaa,0xc4,0x68,0x34,0x62,0x3b,0x58,0xe5,0xdd,0x7e,0x62,0x28,0x25,0xc8,0xcd,0xa4,0xb2,0x3e,0x3d,0x89,0x93,0xba,0xa4,0x40,0x4d,0x62,0x30,0x93,0xf4,0xaf,0x6f,0x55,0xe,0x5f,0xdf,0xa5,0xb2,0x90,0x2c,0x5f,0x8c,0x9e,0xba,0x7e,0x3d,0x5f,0x48,0x43,0xc3,0xee,0x94,0x64,0x38,0xf,0x9f,0xd8,0xa0,0xb3,0x5e,0x33,0x7b,0x97,0xb2,0xb0,0x56,0x46,0x65,0x33,0x6f,0xec,0xce,0x79,0x60,0x1c,0x3a,0xce,0xbc,0xa8,0xa1,0x42,0x4c,0x84,0x9e,0xb5,0x93,0x4a,0x56,0x5c,0x35,0x91,0xfc,0xb0,0x64,0x5e,0xe,0x67,0xe5,0xa5,0xa8,0x87,0x30,0x5f,0x9a,0xab,0xba,0x76,0x3b,0x60,0x4a,0x46,0xc5,0xef,0x89,0x66,0x42,0x16,0x99,0xce,0x9f,0xad,0x66,0x38,0x6f,0x98,0xb2,0xb0,0x63,0x45,0x60,0x30,0x62,0xf7,0xce,0x64,0x6c,0x18,0x31,0xdf,0xb3,0x9b,0xa0,0x35,0x48,0x96,0xa3,0xb4,0x8d,0x41,0x59,0x63,0x39,0x95,0xfa,0xa2,0x61,0x61,0x11,0x65,0xe1,0xa6,0x9e,0x7f,0x2f,0x5b,0xa7,0xb1,0xa3,0x6b,0x3a,0x63,0x4d,0x4e,0xdb,0xe0,0x64,0x69,0x32,0x1b,0xd1,0xc9,0x89,0xa6,0x44,0x36,0x98,0xa2,0xaa,0x98,0x42,0x51,0x72,0x3e,0x7d,0xf6,0xad,0x5b,0x6d,0x1f,0x54,0xe8,0xa6,0x87,0x8c,0x35,0x53,0xa8,0xb0,0xa7,0x74,0x40,0x5e,0x4e,0x4c,0xcc,0xe5,0x72,0x66,0x40,0x20,0xbf,0xd2,0x89,0x9a,0x51,0x39,0x8a,0xa6,0xb6,0x9a,0x49,0x55,0x64,0x3c,0x87,0xf2,0xb5,0x64,0x60,0x22,0x55,0xdf,0xb1,0x89,0x85,0x3a,0x4b,0xa4,0xb7,0xa4,0x83,0x55,0x5d,0x4b,0x42,0xc1,0xf2,0x7f,0x64,0x4b,0x14,0xa6,0xe2,0x8c,0x9c,0x68,0x2b,0x82,0xb7,0xa6,0x9f,0x5f,0x43,0x6a,0x46,0x72,0xf5,0xbc,0x56,0x6b,0x2b,0x40,0xe1,0xc0,0x88,0x8c,0x3b,0x3f,0xa9,0xb9,0x9f,0x90,0x4c,0x4c,0x56,0x48,0xc0,0xf2,0x75,0x5b,0x4f,0x19,0xa8,0xe3,0x92,0x92,0x58,0x34,0x84,0xb0,0xa9,0x9f,0x60,0x48,0x61,0x3a,0x76,0xfc,0xbd,0x54,0x66,0x1f,0x43,0xee,0xbf,0x87,0x82,0x31,0x4b,0xb0,0xb6,0x9f,0x8b,0x46,0x4b,0x5b,0x4f,0xbc,0xfc,0x77,0x48,0x56,0x1b,0xa2,0xf1,0x8f,0x86,0x65,0x33,0x80,0xbd,0xa2,0x9a,0x64,0x40,0x5a,0x3d,0x7b,0xfc,0xbb,0x50,0x5a,0x15,0x56,0xf6,0xae,0x88,0x7e,0x2d,0x58,0xb5,0xa7,0x9e,0x8b,0x3e,0x5c,0x5f,0x3f,0xc0,0xfb,0x6a,0x53,0x4e,0x16,0xb6,0xe6,0x84,0x8f,0x5e,0x30,0x8e,0xba,0x9f,0x96,0x53,0x4a,0x6b,0x3a,0x85,0xff,0xa2,0x48,0x57,0xd,0x6b,0xf9,0xa2,0x8f,0x79,0x28,0x63,0xb6,0xa2,0x9f,0x82,0x3f,0x5f,0x57,0x47,0xcc,0xf3,0x65,0x47,0x43,0x1c,0xb6,0xf1,0x8d,0x7b,0x54,0x38,0x8b,0xc4,0x9d,0x81,0x5a,0x51,0x56,0x3d,0xa4,0xff,0x87,0x44,0x4a,0xd,0x95,0xfd,0x92,0x8d,0x6e,0x25,0x79,0xbb,0x99,0xa1,0x7b,0x37,0x67,0x56,0x4f,0xdf,0xe4,0x46,0x4a,0x43,0x27,0xd9,0xe1,0x7a,0x7a,0x51,0x3c,0x9f,0xbd,0x90,0x7b,0x53,0x55,0x44,0x4f,0xd6,0xe4,0x54,0x4e,0x32,0x29,0xdf,0xce,0x6f,0xa1,0x4f,0x34,0xaf,0x99,0x83,0xb4,0x56,0x45,0x74,0x2e,0x80,0xff,0x98,0x35,0x5d,0x1a,0x73,0xfe,0x97,0x78,0x82,0x39,0x63,0xb5,0x8f,0x9a,0x77,0x54,0x67,0x32,0x6e,0xff,0xac,0x38,0x5c,0x1e,0x6c,0xff,0x90,0x6f,0x8f,0x37,0x69,0xb8,0x71,0x99,0x9e,0x42,0x6f,0x44,0x31,0xdf,0xe8,0x3c,0x47,0x48,0x2f,0xe6,0xd0,0x56,0x87,0x73,0x45,0xa1,0x96,0x77,0xa7,0x67,0x61,0x4c,0x2a,0xba,0xf8,0x50,0x39,0x54,0x31,0xd8,0xd8,0x4b,0x89,0x85,0x4c,0x93,0x8b,0x76,0xad,0x6e,0x61,0x5f,0x1d,0x94,0xff,0x72,0x28,0x69,0x36,0x9f,0xef,0x63,0x74,0xa0,0x5f,0x6c,0x88,0x7d,0xa8,0x88,0x65,0x65,0x18,0x5f,0xff,0xa9,0x1b,0x60,0x40,0x6c,0xfe,0x7d,0x5f,0xab,0x6c,0x68,0x7e,0x68,0xaa,0xa8,0x5b,0x6d,0x28,0x2a,0xeb,0xe0,0x1f,0x41,0x5d,0x4e,0xe9,0xab,0x4e,0x9f,0x8f,0x65,0x6c,0x68,0x9e,0xb3,0x66,0x70,0x43,0x13,0xb9,0xff,0x4e,0x28,0x77,0x4c,0xb6,0xc5,0x4c,0x90,0xb2,0x75,0x61,0x5a,0x89,0xce,0x75,0x5d,0x5a,0xb,0x91,0xff,0x6e,0x1c,0x7b,0x49,0x9e,0xd6,0x47,0x8a,0xc9,0x7a,0x5e,0x50,0x6e,0xd3,0x92,0x55,0x66,0x19,0x66,0xfc,0xa5,0x26,0x6f,0x6e,0x77,0xc3,0x64,0x7a,0xc4,0x85,0x5d,0x57,0x6e,0xcd,0x9b,0x3f,0x73,0x38,0x4d,0xfc,0xb4,0x14,0x80,0x85,0x5a,0xc8,0x65,0x67,0xe1,0x89,0x52,0x67,0x62,0xb5,0xb3,0x4b,0x7b,0x56,0x35,0xdb,0xcd,0x21,0x6c,0xa4,0x5b,0xa1,0x6d,0x56,0xd8,0xac,0x50,0x60,0x6f,0xa9,0xb8,0x58,0x70,0x61,0x31,0xcd,0xd4,0x1f,0x74,0xb1,0x54,0x9c,0x6d,0x4b,0xe0,0xb8,0x52,0x60,0x61,0xa1,0xbb,0x4e,0x6d,0x81,0x38,0xb7
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
void loop(){
	char file_charr[6] = {0};
	int touched = scanbutton();
	
	if(touched != -1){
		String format = ".wav";
		String file_string = touched + format;	//0.wav ~ 7.wav
		file_string.toCharArray(file_charr, 6);	//convert filename to char array file_charr
		
		if(SDCARD_EN){			//sdcard init success
			Serial.print(F("tmrpcm play"));
			Serial.println(file_charr);
			tmrpcm.play(file_charr);
			while(tmrpcm.isPlaying());
			tmrpcm.disable();					//disables everytime finished playing
		}
		else{					//no sdcard
			digitalWrite(13,HIGH);				//won't be toggled by SPI CLK
			play(sdcard_data, sdcard_length);
			play(notfound_data, notfound_length);
			digitalWrite(13,LOW);
		}
	}    
}

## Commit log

2016-11-11 library issue fixed
    switched to original CapacitiveSensor library instead of the costomized
    one
    [SDCARD_Playback.ino]
2017-07-07 reorganize hardware resource
    [SD2DIPSPI.brd, SD2DIPSPI.sch]

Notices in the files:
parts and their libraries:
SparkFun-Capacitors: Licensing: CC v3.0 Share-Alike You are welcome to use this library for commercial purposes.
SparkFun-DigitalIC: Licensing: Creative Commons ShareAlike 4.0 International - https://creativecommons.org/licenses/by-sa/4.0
